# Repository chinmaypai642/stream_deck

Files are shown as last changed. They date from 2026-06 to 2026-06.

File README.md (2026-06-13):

# Deck

A custom ESP32-S3 control deck for Spotify and desktop shortcuts. The deck uses capacitive touch buttons, a rotary encoder, and a 1.3 inch OLED display to control playback, browse playlists, launch apps, and show animated now-playing and idle screens.

The hardware enclosure, faceplate, knob, and internal component layout were designed from scratch in SolidWorks.

## Features

- Spotify playback controls that work while Spotify is foregrounded, minimized, or running in the background
- USB HID media-control fallback for play/pause, next, previous, and seek controls
- Rotary encoder for volume, menu navigation, and item selection
- OLED now-playing screen with title, artist, progress, volume, and playback state
- Animated OLED screens including waveform, flames, clock, vinyl, data rain, and blinking eyes
- Vinyl-style transition animation for next and previous track actions
- Playlist browser with Liked Songs pinned at the top
- Windows companion app with a system tray icon
- Hidden startup mode so the companion can run without keeping PowerShell open
- Custom CAD files for the enclosure and knob

## Hardware

- ESP32-S3 Super Mini
- 5 capacitive touch buttons
- Rotary encoder with push button
- 1.3 inch SH1106 OLED display
- Custom 3D printed enclosure
- Custom 3D printed volume knob

There are no LEDs, LED strips, voice changer modules, or extra macro deck parts required for this build.

## Controls

| Input | Action |
| --- | --- |
| Touch 1 | Seek back 5 seconds |
| Touch 2 | Previous track |
| Touch 3 | Play / pause |
| Touch 4 | Next track |
| Touch 5 | Seek forward 5 seconds |
| Rotate knob | Volume up / down or menu scroll |
| Short-press knob | Mute / unmute or select menu item |
| Long-press knob | Open app launcher |
| Long-press touch 2 | Change now-playing animation style |
| Long-press touch 4 | Open Spotify playlist browser |

## App Launcher

Long-press the rotary encoder button to open the app launcher on the OLED. Rotate the knob to move through the list and press the knob once to open the selected app.

Default launcher items:

```text
1 Spotify
2 Terminal Admin
3 Files
4 Opera
5 WhatsApp
6 Codex
7 Idle Mode
```

## Spotify Playlist Browser

Long-press touch 4 in Spotify mode to open the playlist browser.

```text
Rotate knob -> scroll
Press knob  -> open playlist or play selected song
Touch 5     -> back / exit
```

Liked Songs is pinned at the top of the playlist list. Other Spotify playlists are loaded through the Spotify Web API.

The first Spotify API use may open a browser login page. After approval, the companion stores a local `spotify_token.json` file. This token file is ignored by Git and should not be uploaded.

## OLED Screens

Idle animations:

```text
Waveform
Flames
Clock
Vinyl
Data Rain
Blinking Eyes
```

Now-playing screens include a compact track display and animated vinyl-style playback views. When playback is paused for more than a few seconds, the deck can return to idle mode.

## Wiring

```text
OLED SDA  -> GPIO7
OLED SCL  -> GPIO8

Encoder CLK -> GPIO1
Encoder DT  -> GPIO2
Encoder SW  -> GPIO3

Touch 1 -> GPIO11
Touch 2 -> GPIO10
Touch 3 -> GPIO12
Touch 4 -> GPIO9
Touch 5 -> GPIO13
```

## Firmware Setup

Open the firmware in Arduino IDE:

```text
firmware/deck_s3/deck_s3.ino
```

Recommended Arduino IDE settings:

```text
Board: ESP32S3 Dev Module
USB CDC On Boot: Enabled
USB Mode: USB-OTG / TinyUSB if using native USB HID
```

Required Arduino libraries:

```text
Adafruit GFX Library
Adafruit SH110X
Adafruit BusIO
```

Upload the sketch to the ESP32-S3 after closing any Serial Monitor that may be using the COM port.

## Windows Companion Setup

Install the Python dependencies:

```powershell
pip install -r requirements_spotify_deck.txt
```

Start the companion with a visible console:

```text
Start_Deck.bat
```

Start it silently in the background:

```text
Start_Deck_Hidden.bat
```

Stop the companion before uploading firmware again:

```text
Stop_Deck.bat
```

The companion creates a Deck system tray icon with shortcuts for opening Spotify, reconnecting the deck, opening the project folder, and exiting the companion.

## Optional Startup Install

To make the companion start automatically when Windows logs in, run:

```text
Install_Deck_Startup.bat
```

To remove it from Windows startup:

```text
Uninstall_Deck_Startup.bat
```

## Spotify Developer Setup

For playlist browsing and richer Spotify status, create a Spotify Developer app and enable the Web API. Add a local redirect URI in the Spotify dashboard, then add the client ID to the companion configuration.

The companion uses these Spotify scopes:

```text
user-read-playback-state
user-read-currently-playing
user-modify-playback-state
user-library-read
playlist-read-private
playlist-read-collaborative
```

Do not commit `spotify_token.json`, logs, build folders, or packaged binaries with personal data.

## Project Structure

```text
firmware/deck_s3/          ESP32-S3 firmware
deck_project_cad_files/    SolidWorks, STEP, and STL design files
spotify_deck_win.py        Windows companion app
requirements_spotify_deck.txt
Start_Deck.bat
Start_Deck_Hidden.bat
Stop_Deck.bat
Install_Deck_Startup.bat
Uninstall_Deck_Startup.bat
```

## CAD Files

The repository includes CAD files for the enclosure, bottom plate, capacitive touch plates, and volume knob. The design was iterated around real component fit, wiring space, 3D printing tolerances, and PLA shrinkage.

## Notes

This is a personal hardware project, so pin mappings, app paths, and Spotify setup may need small changes for another computer or deck layout.

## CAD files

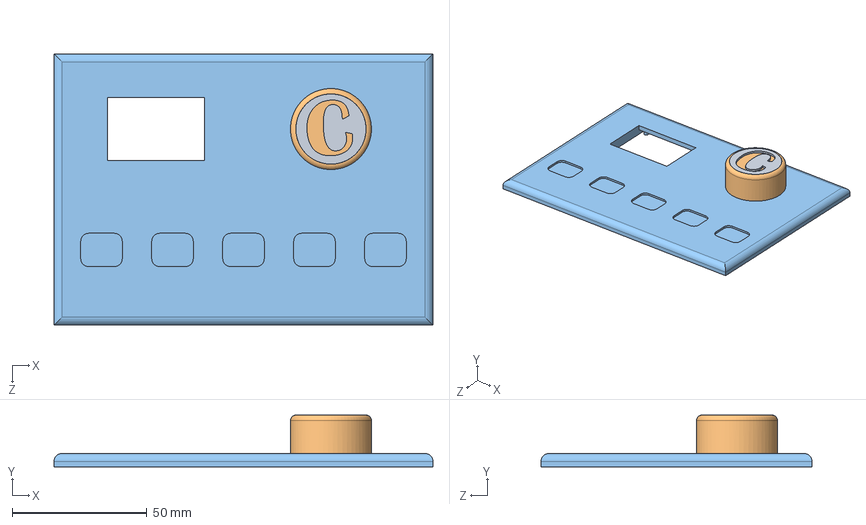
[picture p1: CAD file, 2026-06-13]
deck_project_cad_files/spotifydeckassembly.SLDASM
140.4 x 19.2 x 100.4 mm
TOP
VOLUME KNOB
VOLUMEKNOBTOP

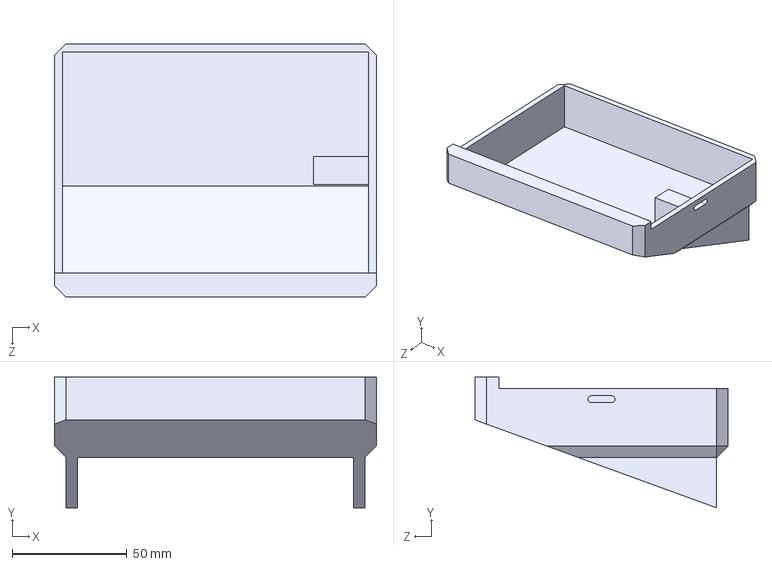
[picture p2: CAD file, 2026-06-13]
deck_project_cad_files/BOTTOM.STEP
140.4 x 57.0 x 110.4 mm

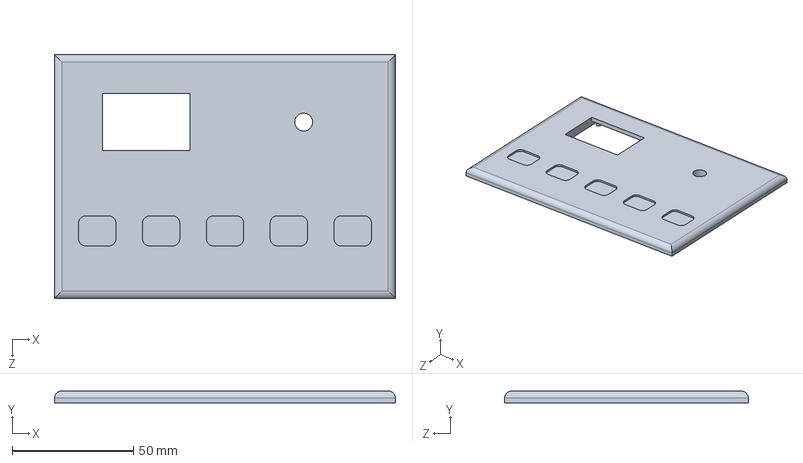
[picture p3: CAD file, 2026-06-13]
deck_project_cad_files/TOP.SLDPRT
140.4 x 5.00 x 100.4 mm

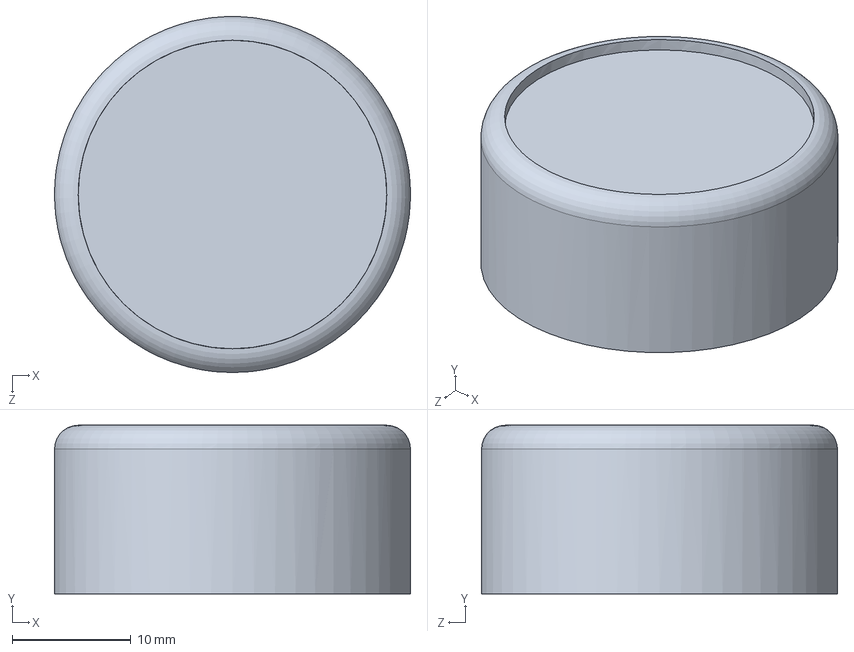
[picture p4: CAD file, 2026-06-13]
deck_project_cad_files/VOLUME KNOB.SLDPRT
30.0 x 14.2 x 30.0 mm

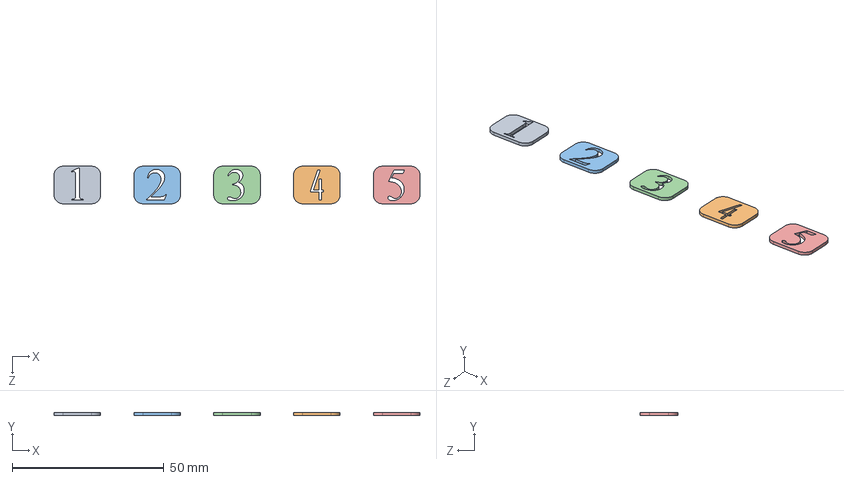
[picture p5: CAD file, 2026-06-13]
deck_project_cad_files/CAPACITOR PLATES.STEP
120.6 x 1.00 x 12.4 mm

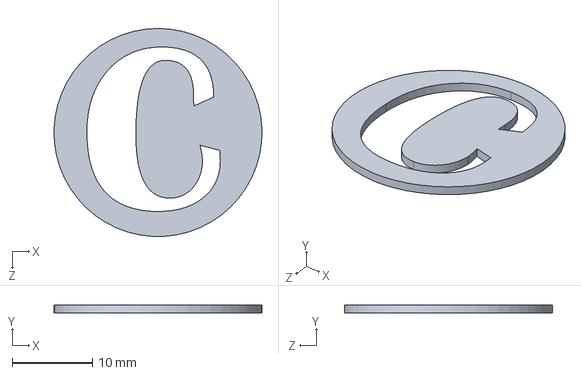
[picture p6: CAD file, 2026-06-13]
deck_project_cad_files/VOLUMEKNOBTOP.SLDPRT
26.0 x 1.00 x 26.0 mm

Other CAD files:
deck_project_cad_files/TOPfinal2.STL
deck_project_cad_files/BOTTOM.SLDPRT
deck_project_cad_files/CAPACITOR PLATES.SLDPRT
deck_project_cad_files/TOP.STL
deck_project_cad_files/VOLUME KNOB.STL
deck_project_cad_files/VOLUMEKNOBTOP.STL

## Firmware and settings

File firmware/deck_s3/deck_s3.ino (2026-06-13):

/*  PROJECT: DECK S3 - Wired PC Control Panel
    BOARD: ESP32-S3
*/

#include "config.h"
#include "display.h"
#include "hid_controls.h"
#include "inputs.h"
#include "leds.h"
#include <Arduino.h>

void setup() {
  // ESP32-S3 Native USB can be tricky.
  // We use Serial for communication.
  Serial.begin(115200);
  randomSeed((uint32_t)esp_random());

  // Wait for USB connection
  unsigned long t = millis();
  while (!Serial && millis() - t < 3000) {
    delay(10);
  }

  initDisplay();
  initHidControls();
  initLeds();
  initInputs();

  delay(500);
  showOverlay("RUBEN DECK");
  Serial.println(F("READY"));
  setLedMode(LED_MODE_RAINBOW);
}

String cmdBuffer = "";
unsigned long lastSerialTime = 0;
#define SERIAL_TIMEOUT_MS 3000

void loop() {
  updateInputs();
  updateLeds();
  updateDisplay();

  // Serial command processing
  while (Serial.available()) {
    char c = Serial.read();
    if (c == '\n' || c == '\r') {
      if (cmdBuffer.length() > 0) {
        lastSerialTime = millis();
        cmdBuffer.trim();
        processCommand(cmdBuffer);
        cmdBuffer = "";
      }
    } else {
      cmdBuffer += c;
      if (cmdBuffer.length() > 256)
        cmdBuffer = "";
    }
  }

  // Small yield to keep S3 happy
  yield();
}

void processCommand(String cmd) {
  if (cmd.startsWith("LED:")) {
    String data = cmd.substring(4);
    if (data == "OFF")
      setLedMode(LED_MODE_OFF);
    else if (data == "ON" || data == "RAINBOW")
      setLedMode(LED_MODE_RAINBOW);
    else if (data == "BPM")
      setLedMode(LED_MODE_BPM);
    else if (data == "CONFETTI")
      setLedMode(LED_MODE_CONFETTI);
    else if (data == "JUGGLE")
      setLedMode(LED_MODE_JUGGLE);
    else if (data == "WHITE")
      setLedMode(LED_MODE_WHITE);
    else if (data == "CYCLE") {
      cycleLedMode();
    } else if (data == "MUTE")
      setMuteFlash(true);
    else if (data == "UNMUTE")
      setMuteFlash(false);
    else if (data.startsWith("VOL,")) {
      char dir;
      int pct;
      if (sscanf(data.c_str(), "VOL,%c,%d", &dir, &pct) == 2)
        showLedVolumeBar(pct, dir == '+');
    }
  } else if (cmd.startsWith("MEDIA:")) {
    String data = cmd.substring(6);
    if (data == "STOP") {
      clearNowPlaying();
      return;
    }
    int s1 = data.indexOf('|');
    int s2 = data.indexOf('|', s1 + 1);
    int s3 = data.indexOf('|', s2 + 1);
    if (s1 > 0 && s2 > 0 && s3 > 0) {
      setNowPlaying(data.substring(0, s1), data.substring(s1 + 1, s2),
                    data.substring(s2 + 1, s3).toInt(),
                    data.substring(s3 + 1).toInt());
    }
  } else if (cmd.startsWith("STATUS:")) {
    int status = cmd.substring(7).toInt();
    setPlaybackStatus(status == 1);
  } else if (cmd.startsWith("OLED:")) {
    String data = cmd.substring(5);
    if (data.startsWith("VOL:")) {
      int c1 = data.indexOf(',');
      int c2 = data.indexOf(',', c1 + 1);
      if (c1 > 0 && c2 > 0) {
        setVolumeStatus(data.substring(4, c1),
                        data.substring(c1 + 1, c2).toInt(),
                        data.substring(c2 + 1) == "1");
      }
    } else if (data.startsWith("APPMENU:")) {
      String menuData = data.substring(8);
      if (menuData == "OFF") {
        clearAppMenu();
      } else {
        setAppMenuIndex(menuData.toInt());
      }
    } else if (data.startsWith("IDLEMENU:")) {
      String menuData = data.substring(9);
      if (menuData == "OFF") {
        clearIdleMenu();
      } else {
        setIdleMenuIndex(menuData.toInt());
      }
    } else if (data.startsWith("NPSTYLEMENU:")) {
      String menuData = data.substring(12);
      if (menuData == "OFF") {
        clearNowPlayingStyleMenu();
      } else {
        setNowPlayingStyleMenuIndex(menuData.toInt());
      }
    } else if (data.startsWith("QUEUE:")) {
      String queueData = data.substring(6);
      if (queueData == "OFF") {
        clearQueueMenu();
      } else {
        setQueueMenuFromPayload(queueData);
      }
    } else if (data.startsWith("IDLE:")) {
      setIdleAnimation(data.substring(5).toInt());
    } else if (data.startsWith("NPSTYLE:")) {
      setNowPlayingStyle(data.substring(8).toInt());
    } else if (data.startsWith("TRANSITION:")) {
      runTrackTransition(data.substring(11));
    } else if (data.startsWith("MODE:")) {
      setModeText(data.substring(5));
    } else if (data.startsWith("FOOTER:")) {
      setFooterText(data.substring(7));
    } else if (data.startsWith("CLOCK:")) {
      setClockText(data.substring(6));
    } else if (data == "CLEAR") {
      showOverlay("");
    } else {
      showOverlay(data);
    }
  } else if (cmd.startsWith("IMG:")) {
    int firstColon = cmd.indexOf(':');
    int secondColon = cmd.indexOf(':', firstColon + 1);
    if (firstColon != -1 && secondColon != -1) {
      int chunkIdx = cmd.substring(firstColon + 1, secondColon).toInt();
      String hex = cmd.substring(secondColon + 1);
      receiveImageChunk(chunkIdx, hex);
    }
  } else if (cmd.startsWith("HID:")) {
    String data = cmd.substring(4);
    bool ok = sendHidCommand(data);
    Serial.print(F("HID:"));
    Serial.print(data);
    Serial.println(ok ? F(":OK") : F(":FAIL"));
  }

  // Connection watchdog: if no serial for 10s, clear display to eyes
  if (millis() - lastSerialTime > SERIAL_TIMEOUT_MS) {
    if (lastSerialTime != 0) { // Only if we once had a connection
      clearNowPlaying();
    }
  }
}

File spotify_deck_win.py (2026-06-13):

"""
Deck Windows companion.

This is the laptop-side bridge for:
- ESP32-S3 Super Mini
- 5 TTP223 capacitive buttons
- 1 rotary encoder with push switch
- 1.3 inch 128x64 OLED

The ESP32 sends simple serial events:
  BTN:1  Seek back 5 seconds
  BTN:2  Previous
  BTN:3  Play/Pause
  BTN:4  Next
  BTN:5  Seek forward 5 seconds
  ENC:+1 Spotify volume up
  ENC:-1 Spotify volume down
  CLICK:short Spotify mute/unmute

This app runs quietly in the background and controls Spotify even when Spotify
is minimized or behind another window. Spotify must still be open.
"""

import asyncio
import base64
import ctypes
import hashlib
import http.server
import json
import os
import secrets
import socket
import subprocess
import sys
import threading
import time
import urllib.error
import urllib.parse
import urllib.request
import webbrowser
from ctypes import wintypes
from pathlib import Path

import serial
import serial.tools.list_ports
import pystray
from comtypes import CoInitialize
from PIL import Image, ImageDraw
from pycaw.pycaw import AudioUtilities, IAudioMeterInformation, ISimpleAudioVolume
from winsdk.windows.media.control import (
    GlobalSystemMediaTransportControlsSessionManager as MediaManager,
)
from winsdk.windows.media.control import GlobalSystemMediaTransportControlsSessionPlaybackStatus


SERIAL_BAUD = 115200
SPOTIFY_PROCESS = "spotify.exe"
SPOTIFY_APP_HINT = "spotify"
VOLUME_STEP = 0.05
SEEK_STEP_MS = 5000
if getattr(sys, "frozen", False):
    APP_DIR = Path(sys.executable).resolve().parent
    if APP_DIR.name.lower() == "dist":
        APP_DIR = APP_DIR.parent
else:
    APP_DIR = Path(__file__).resolve().parent

LOG_PATH = APP_DIR / "spotify_deck.log"
LOCK_PORT = 49631
SPOTIFY_CLIENT_ID = "23690a9a484041a68decf948a766422c"
SPOTIFY_REDIRECT_URI = "http://127.0.0.1:8765/callback"
SPOTIFY_SCOPES = "user-read-playback-state user-read-currently-playing user-modify-playback-state user-library-read playlist-read-private playlist-read-collaborative"
SPOTIFY_AUTH_URL = "https://accounts.spotify.com/authorize"
SPOTIFY_TOKEN_URL = "https://accounts.spotify.com/api/token"
SPOTIFY_API_BASE = "https://api.spotify.com/v1"
SPOTIFY_API_TIMEOUT_SECONDS = 5
TOKEN_PATH = APP_DIR / "spotify_token.json"
SPOTIFY_APP_ID = r"SpotifyAB.SpotifyMusic_zpdnekdrzrea0!Spotify"
OPERA_APP_ID = r"OperaSoftware.OperaGXWebBrowser.1747169853"
WHATSAPP_APP_ID = r"5319275A.WhatsAppDesktop_cv1g1gvanyjgm!App"
CODEX_APP_ID = r"shell:AppsFolder\OpenAI.Codex_2p2nqsd0c76g0!App"
CODEX_RAW_APP_ID = r"OpenAI.Codex_2p2nqsd0c76g0!App"
CODEX_EXE_CANDIDATES = [
    Path(os.environ.get("LOCALAPPDATA", "")) / "Packages" / "OpenAI.Codex_2p2nqsd0c76g0" / "LocalCache" / "Local" / "OpenAI" / "Codex" / "bin" / "codex.exe",
    Path(os.environ.get("LOCALAPPDATA", "")) / "OpenAI" / "Codex" / "bin" / "7dea4a003bc76627" / "codex.exe",
]
PROCESS_QUERY_LIMITED_INFORMATION = 0x1000
SW_MAXIMIZE = 3
SW_RESTORE = 9
SWP_NOSIZE = 0x0001
SWP_NOMOVE = 0x0002
SWP_SHOWWINDOW = 0x0040
VK_MEDIA_NEXT = 0xB0
VK_MEDIA_PREV = 0xB1
VK_MEDIA_PLAY_PAUSE = 0xB3

user32 = ctypes.windll.user32
kernel32 = ctypes.windll.kernel32
WNDENUMPROC = ctypes.WINFUNCTYPE(wintypes.BOOL, wintypes.HWND, wintypes.LPARAM)
user32.EnumWindows.argtypes = [WNDENUMPROC, wintypes.LPARAM]
user32.EnumWindows.restype = wintypes.BOOL
user32.IsWindowVisible.argtypes = [wintypes.HWND]
user32.IsWindowVisible.restype = wintypes.BOOL
user32.GetWindowTextLengthW.argtypes = [wintypes.HWND]
user32.GetWindowTextLengthW.restype = ctypes.c_int
user32.GetWindowTextW.argtypes = [wintypes.HWND, wintypes.LPWSTR, ctypes.c_int]
user32.GetWindowTextW.restype = ctypes.c_int
user32.GetWindowThreadProcessId.argtypes = [wintypes.HWND, ctypes.POINTER(wintypes.DWORD)]
user32.GetWindowThreadProcessId.restype = wintypes.DWORD
user32.ShowWindow.argtypes = [wintypes.HWND, ctypes.c_int]
user32.ShowWindow.restype = wintypes.BOOL
user32.SetForegroundWindow.argtypes = [wintypes.HWND]
user32.SetForegroundWindow.restype = wintypes.BOOL
user32.GetForegroundWindow.argtypes = []
user32.GetForegroundWindow.restype = wintypes.HWND
user32.BringWindowToTop.argtypes = [wintypes.HWND]
user32.BringWindowToTop.restype = wintypes.BOOL
user32.SetActiveWindow.argtypes = [wintypes.HWND]
user32.SetActiveWindow.restype = wintypes.HWND
user32.SetWindowPos.argtypes = [wintypes.HWND, wintypes.HWND, ctypes.c_int, ctypes.c_int, ctypes.c_int, ctypes.c_int, wintypes.UINT]
user32.SetWindowPos.restype = wintypes.BOOL
user32.AttachThreadInput.argtypes = [wintypes.DWORD, wintypes.DWORD, wintypes.BOOL]
user32.AttachThreadInput.restype = wintypes.BOOL
kernel32.OpenProcess.argtypes = [wintypes.DWORD, wintypes.BOOL, wintypes.DWORD]
kernel32.OpenProcess.restype = wintypes.HANDLE
kernel32.GetCurrentThreadId.argtypes = []
kernel32.GetCurrentThreadId.restype = wintypes.DWORD
kernel32.QueryFullProcessImageNameW.argtypes = [wintypes.HANDLE, wintypes.DWORD, wintypes.LPWSTR, ctypes.POINTER(wintypes.DWORD)]
kernel32.QueryFullProcessImageNameW.restype = wintypes.BOOL
kernel32.CloseHandle.argtypes = [wintypes.HANDLE]
kernel32.CloseHandle.restype = wintypes.BOOL

serial_port = None
lock_socket = None
main_loop = None
tray_icon = None
last_command_times = {}
last_title = None
last_artist = None
last_position = None
last_duration = None
last_status = None
last_volume_status = None
last_clock_min = -1
last_touch_long_time = 0
last_media_timeout_log = 0
token_refresh_block_until = 0
paused_since = None
deck_idle = True
active_app_mode = "spotify"
manual_idle_requested = False
app_menu_active = False
app_menu_index = 0
idle_menu_active = False
idle_menu_index = 0
np_style_menu_active = False
np_style_menu_index = 0
liked_songs_menu_active = False
liked_songs_index = 0
liked_songs_items = []
playlist_browser_active = False
playlist_browser_level = "playlists"
playlist_index = 0
playlist_items = []
playlist_track_index = 0
playlist_track_items = []
idle_animation_index = 0
now_playing_style_index = 0
APP_MENU_ITEMS = [
    "Spotify",
    "Terminal Admin",
    "Files",
    "Opera",
    "WhatsApp",
    "Codex",
    "Idle Mode",
]
IDLE_MENU_ITEMS = [
    "Waveform",
    "Flames",
    "Clock",
    "Vinyl",
    "Data Rain",
    "Blinking Eyes",
]
NP_STYLE_MENU_ITEMS = [
    "Vinyl",
    "Minimal",
    "Big Title",
]
PLAYLIST_MENU_NAMES = []


def log(message):
    line = f"{time.strftime('%Y-%m-%d %H:%M:%S')}  {message}"
    try:
        print(line)
    except Exception:
        pass
    try:
        with LOG_PATH.open("a", encoding="utf-8") as f:
            f.write(line + "\n")
    except Exception:
        pass


def acquire_single_instance_lock():
    global lock_socket
    lock_socket = socket.socket(socket.AF_INET, socket.SOCK_STREAM)
    lock_socket.setsockopt(socket.SOL_SOCKET, socket.SO_REUSEADDR, 0)
    try:
        lock_socket.bind(("127.0.0.1", LOCK_PORT))
        lock_socket.listen(1)
        return True
    except OSError:
        return False
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
